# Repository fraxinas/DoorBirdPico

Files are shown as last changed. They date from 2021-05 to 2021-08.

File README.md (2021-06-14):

# DoorBirdPico

(CC) 2021 by Andreas Frisch <fraxinas@purplegecko.de>

## OwO what's this?

**`DoorBirdPico` is a custom Raspberry Pi Pico PCB design and code to add functionality to the DoorBird Voip entryphone.**

## Hardware Features

- ports for 3 RGB-lit doorbell buttons
- ports for 2 reed sensors (door/letterbox)
- hardware debouncing
- power / UART communication with Doorbird D2100E
- 2 input ports for the Doorbird relays
- 1 potential-free relay output (for door opener)
- RS485 transceiver

## Software

- using Rasperry Pi Pico C API
- interrupt services routines for buttons
- color-fading PWM

## Project Diary

| Date | Version | Milestone |
| :--- | :--- | :--- |
| 2021-04-06 | | Pico on Breadboard, pushbutton irq & pwm |
| 2021-04-13 | | Implemented UART communication with Doorbird |
| 2021-04-16 | | Started git repository |
| 2021-05-12 | v0.1 | Commission of 1st prototype PCB with aisler.net |
| 2021-06-02 | v0.1 | Received prototype PCB |
| 2021-06-04 | v0.1 | Assembling of prototype PCB |
| 2021-06-06 | v0.2 | Software is essentially ready |

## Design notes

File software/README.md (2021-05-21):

# DoorBirdPico Software

(CC) 2021 by Andreas Frisch <fraxinas@purplegecko.de>

## Prerequisites
Build requirements:
* `cmake`
* `gcc-arm-none-eabi`
* `meta-group-base-devel` (Arch) / `build-essential` (debian)

### Raspberry Pi Pico SDK
* get https://github.com/raspberrypi/pico-sdk
* build following readme
* `export PICO_SDK_PATH="/your-pico-sdk-path"`
 
## Building
```
cd software
cmake . -B build/
cd build
make
```

## Programming
* use https://github.com/raspberrypi/picotool
```
sudo /path-to/picotool/build/picotool load doorbirdpico.uf2
```

## Documentation of Doorbird UART Communication
* UART baud rate is 9600
* startup sequence needs to be answered with registration string within 2 cycles

| Bytes (HEX) | ASCII | Direction | Command |
| :--- | :--- | :--- | :--- |
| 0x0201 | [STX][SOH] | Main -> PICO | Startup sequence |
| 0x4D54545F31345F3030315F3030310D0A | MTT_14_001_001\r\n | PICO -> Main | Registration as Multi Tenant Module |
| 0x313031230D0A | 101#\r\n | PICO -> Main | Button 1 pressed |
| 0x313032230D0A | 102#\r\n | PICO -> Main | Button 2 pressed |
| 0x313...230D0A | 1nn#\r\n | PICO -> Main | Button n pressed |
| 0x313134230D0A | 114#\r\n | PICO -> Main | Button 14 pressed |

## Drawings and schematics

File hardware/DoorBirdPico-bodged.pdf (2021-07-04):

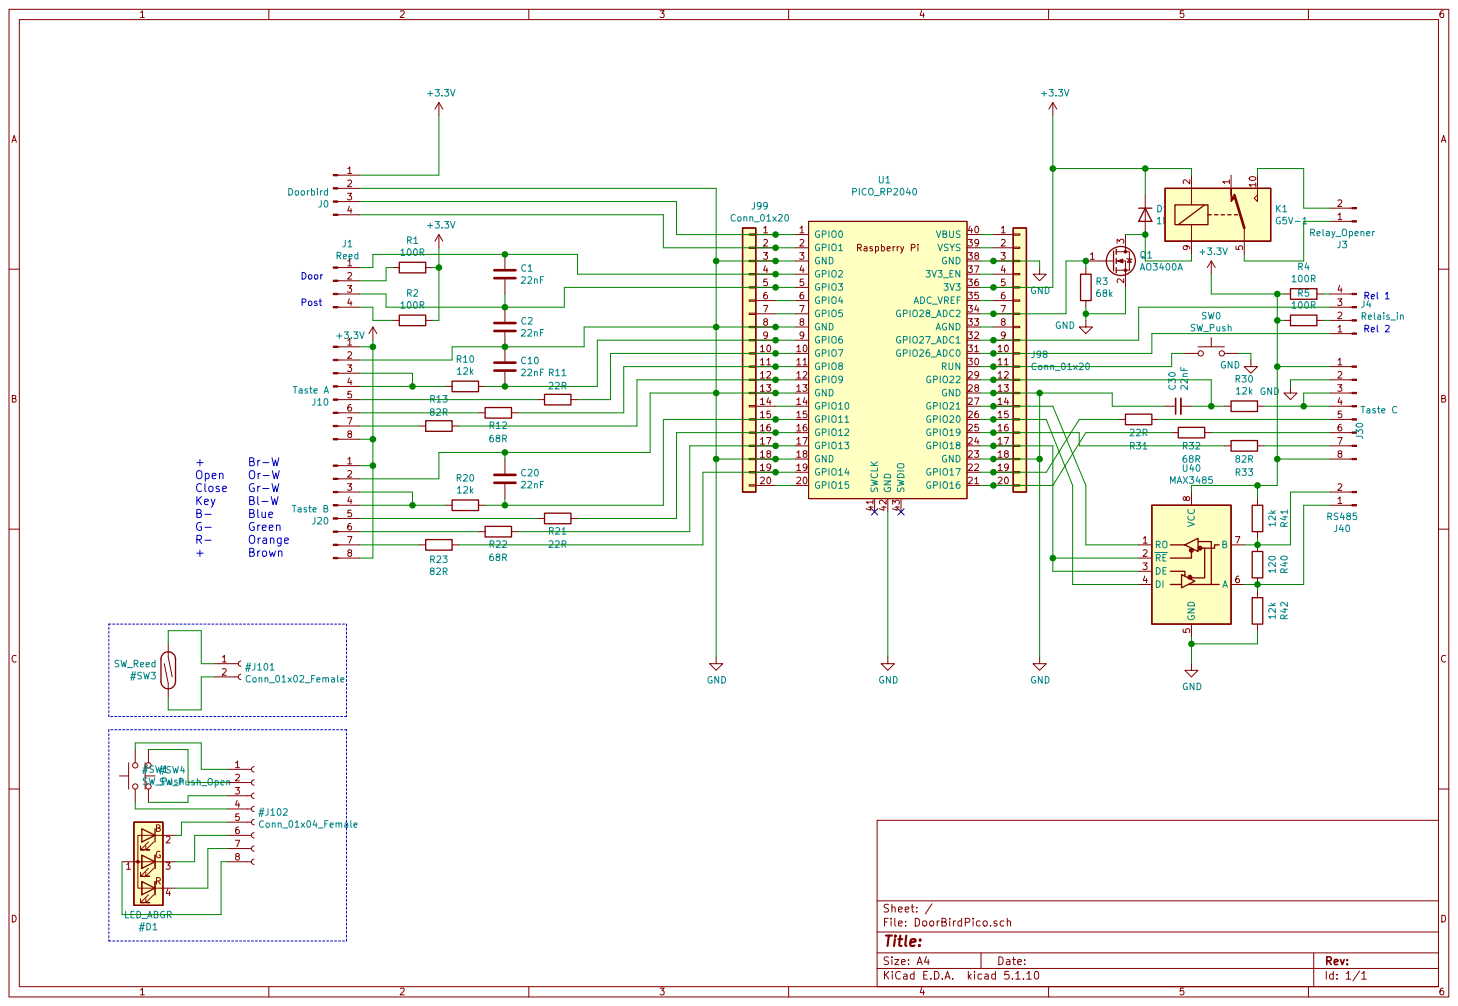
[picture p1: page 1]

10 | 10
11 | 11
12 | 12
13 | 13
14 | 14
15 | 15

17 | 17
18 | 18
19 | 19
20 | 20

Id: 1/1 Title: File: DoorBirdPico.sch Sheet: /

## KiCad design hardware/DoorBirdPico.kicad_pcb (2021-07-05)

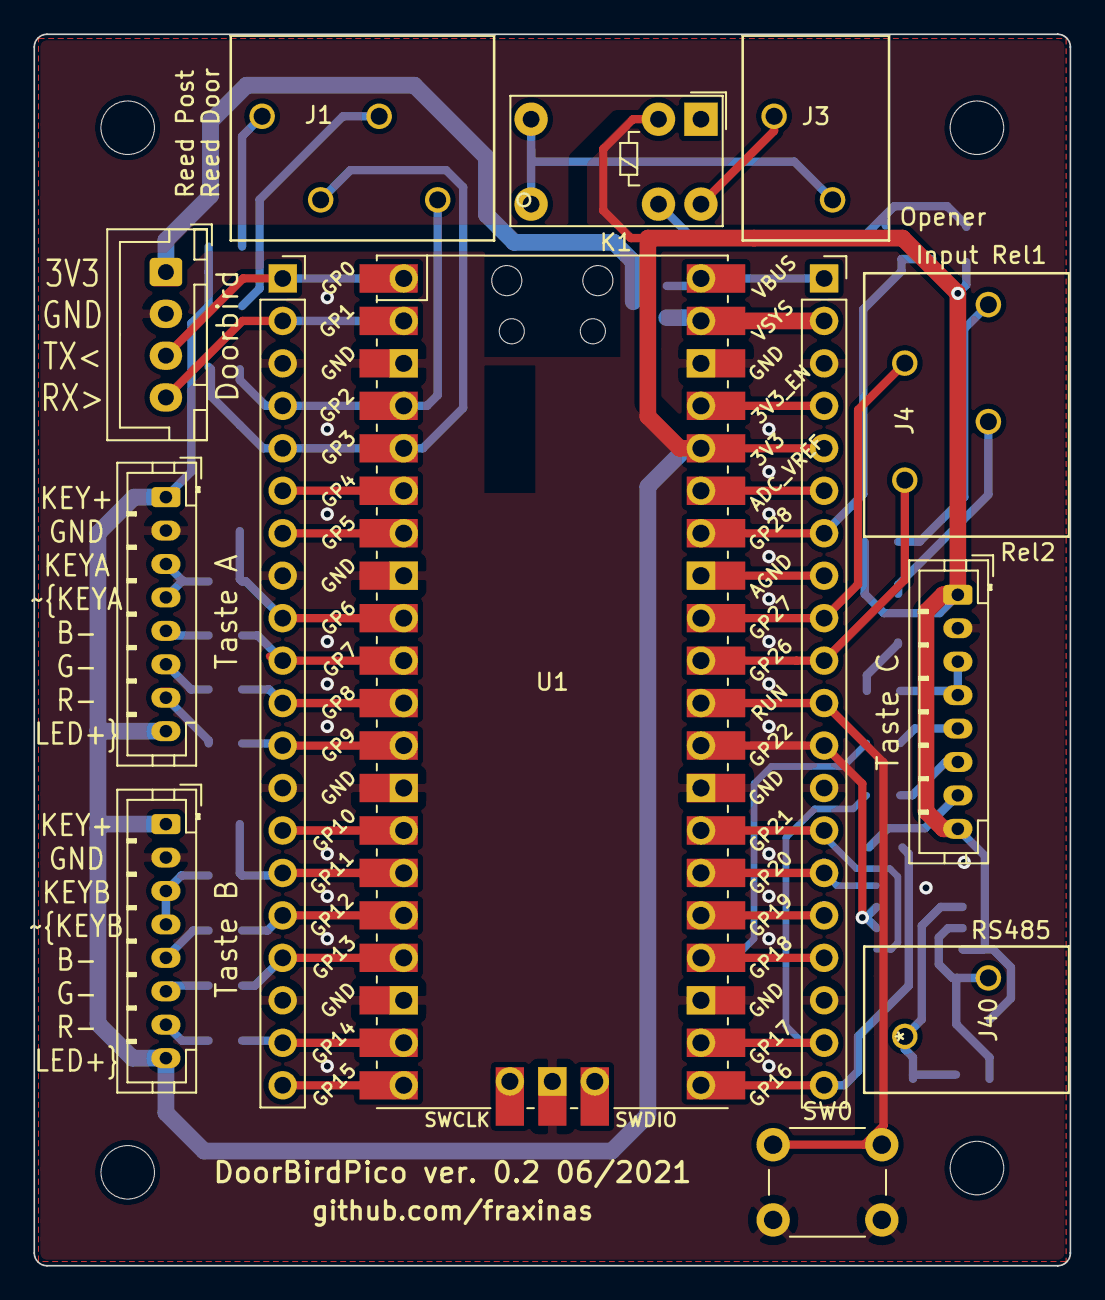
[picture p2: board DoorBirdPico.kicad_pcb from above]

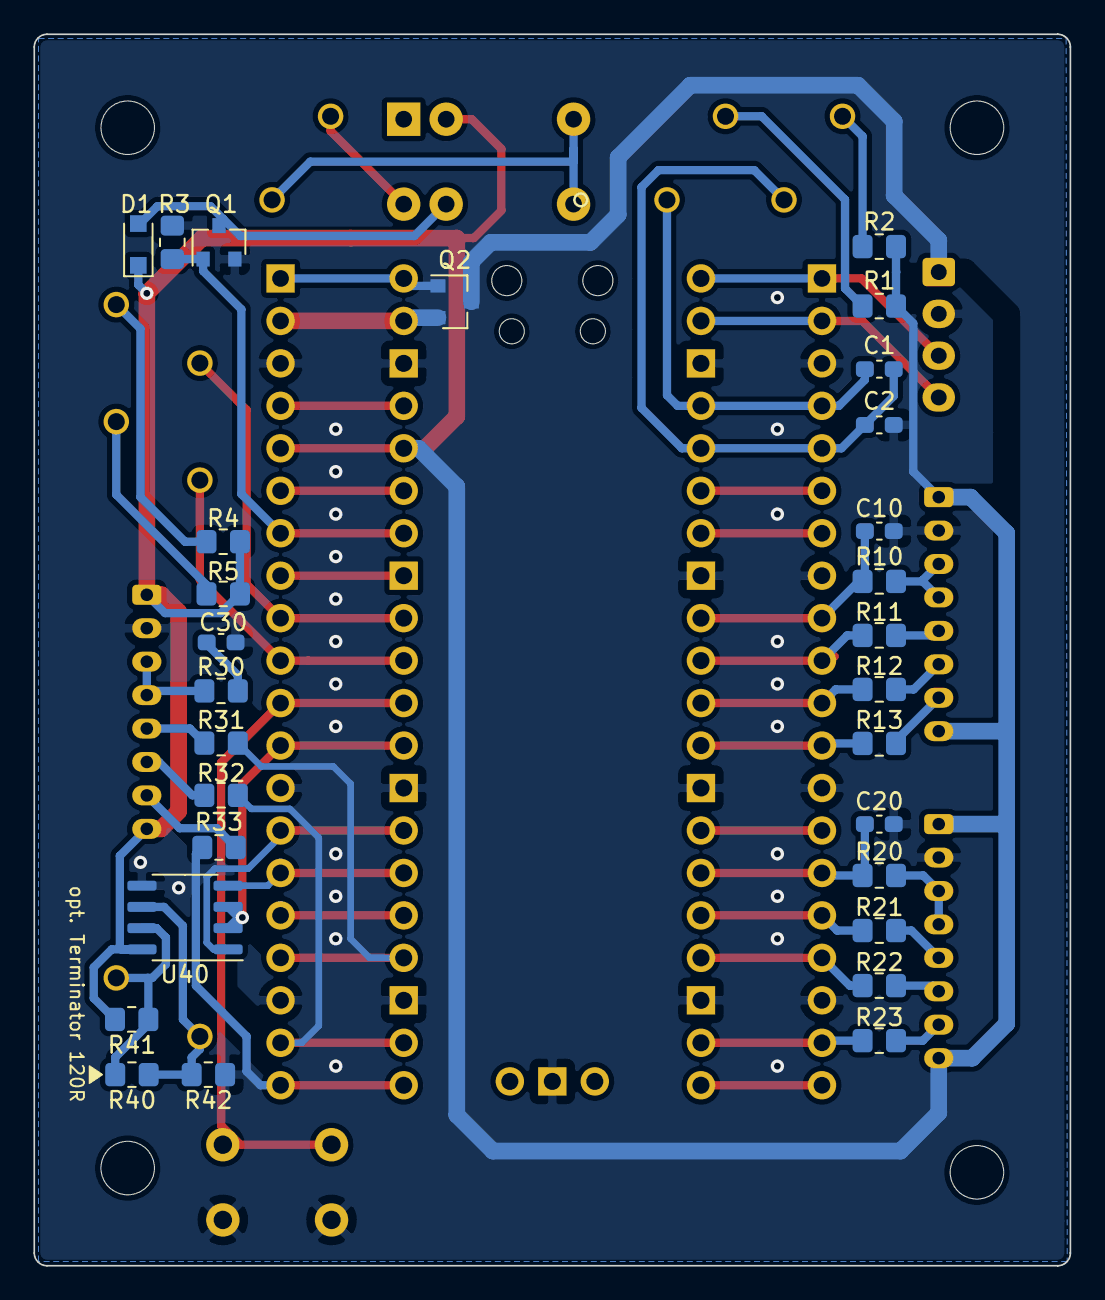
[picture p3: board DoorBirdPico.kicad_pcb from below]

Board: 2 copper layers, 62.0 x 73.7 mm, 42 parts (29 on the bottom side), 57 nets.

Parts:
C1, C2, C10, C20, C30: 22nF; C_0603_1608Metric_Pad1.08x0.95mm_HandSolder
D1: 1N4148WS; D_SOD-323_HandSoldering
J0: Doorbird; JST_XH_B4B-XH-A_1x04_P2.50mm_Vertical
J1: Reed; 250-204
J3: Relay_Opener; 250-202
J4: Relais_in; 250-204
J10: Taste A; JST_PH_B8B-PH-K_1x08_P2.00mm_Vertical
J20: Taste B; JST_PH_B8B-PH-K_1x08_P2.00mm_Vertical
J30: Taste C; JST_PH_B8B-PH-K_1x08_P2.00mm_Vertical
J40: RS485; 250-202
J98, J99: Conn_01x20; PinSocket_1x20_P2.54mm_Vertical
K1: G5V-1; Relay_SPDT_Omron_G5V-1
Q1: AO3400A; SOT-23
Q2: AO3401A; SOT-23
R1, R2, R4, R5: 100R; R_0805_2012Metric_Pad1.20x1.40mm_HandSolder
R3: 68k; R_0805_2012Metric_Pad1.20x1.40mm_HandSolder
R10, R20, R30, R41, R42: 12k; R_0805_2012Metric_Pad1.20x1.40mm_HandSolder
R11, R21, R31: 22R; R_0805_2012Metric_Pad1.20x1.40mm_HandSolder
R12, R22, R32: 68R; R_0805_2012Metric_Pad1.20x1.40mm_HandSolder
R13, R23, R33: 82R; R_0805_2012Metric_Pad1.20x1.40mm_HandSolder
R40: 120; R_0805_2012Metric_Pad1.20x1.40mm_HandSolder
SW0: SW_Push; SW_PUSH_6mm_H5mm
U1: PICO_RP2040; RPi_Pico_SMD_TH
U40: MAX3485; SO-8_3.9x4.9mm_P1.27mm

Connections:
+3V3: D1.1, J10.1, J10.8, J20.1, J20.8, J30.1, J30.8, J98.5, K1.2, R1.1, R2.1, R4.2, R5.2, R41.1, U1.36, U40.8
GND: C2.2, C10.1, C20.1, J0.2, J10.2, J20.2, J30.2, J98.3, J98.13, J98.18, J99.3, J99.8, J99.13, J99.18, Q1.2, R3.2, R42.2, SW0.2, U1.3, U1.8, U1.13, U1.18, U1.23, U1.28, U1.38, U1.42, U40.5
unnamed: C1.1, J1.1, J99.4, U1.4
unnamed: C1.2, C2.1, J1.3, J99.5, U1.5
unnamed: C10.2, J99.9, R10.1, U1.9
unnamed: C20.2, J99.15, R20.1, U1.15
unnamed: C30.2, R30.1
unnamed: D1.2, K1.9, Q1.3
unnamed: J0.1, Q2.3
unnamed: J0.3, J99.1, U1.1
unnamed: J0.4, J99.2, U1.2
unnamed: J1.2, R1.2
unnamed: J1.4, R2.2
unnamed: J3.1, K1.5, K1.6
unnamed: J3.2, K1.10
unnamed: J4.1, J98.10, U1.31
unnamed: J4.2, R5.1
unnamed: J4.3, J98.9, U1.32
unnamed: J4.4, R4.1
unnamed: J10.3, J10.4, R10.2
unnamed: J10.5, R11.1
unnamed: J10.6, R12.1
unnamed: J10.7, R13.1
unnamed: J20.3, J20.4, R20.2
unnamed: J20.5, R21.1
unnamed: J20.6, R22.1
unnamed: J20.7, R23.1
unnamed: J30.3, J30.4, R30.2
unnamed: J30.5, R31.1
unnamed: J30.6, R32.1
unnamed: J30.7, R33.1
unnamed: J40.1, R40.2, R42.1, U40.6
unnamed: J40.2, R40.1, R41.2, U40.7
unnamed: J98.1, Q2.1, U1.40
unnamed: J98.2, Q2.2, U1.39
unnamed: J98.4, U1.37
unnamed: J98.6, U1.35
unnamed: J98.7, Q1.1, R3.1, U1.34
unnamed: J98.8, U1.33
unnamed: J98.11, SW0.1, U1.30
unnamed: J98.12, U1.29, U40.2, U40.3
unnamed: J98.14, U1.27, U40.1
unnamed: J98.15, U1.26, U40.4
unnamed: J98.16, U1.25
unnamed: J98.17, R31.2, U1.24
unnamed: J98.19, R32.2, U1.22
unnamed: J98.20, R33.2, U1.21
unnamed: J99.6, U1.6
unnamed: J99.7, U1.7
unnamed: J99.10, R11.2, U1.10
unnamed: J99.11, R12.2, U1.11
unnamed: J99.12, R13.2, U1.12
unnamed: J99.14, U1.14
unnamed: J99.16, R21.2, U1.16
unnamed: J99.17, R22.2, U1.17
unnamed: J99.19, R23.2, U1.19
unnamed: J99.20, U1.20

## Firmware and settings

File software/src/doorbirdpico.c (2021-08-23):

#include "doorbirdpico.h"

void on_uart_rx()
{
    printf("on_uart_rx... ");
    if (uart_is_readable(UART_ID))
        on_doorbird_rx();

    if (uart_is_readable(RS485_ID))
        on_rs485_rx();
}

void on_doorbird_rx()
{
    printf("on_doorbird_rx... ");
    while (uart_is_readable(UART_ID))
    {
        uint8_t ch = uart_getc(UART_ID);
        printf("0x%02X ", ch);
        if (ch == 0x02)
        {
            ch = uart_getc(UART_ID);
            printf("%02X\n", ch);
            if (ch == 0x01)
            {
                if (uart_is_writable(UART_ID))
                {
                    printf("received startup bytes from Doorbird. Sending UART_INIT_SEQUENCE...\n");
                    uart_puts(UART_ID, UART_INIT_SEQUENCE);
                    printf("'%s' sent successfully!\n", UART_INIT_SEQUENCE);
                    // setup_uart(true);
                    return;
                }
            }
        }
    }
}

rs485_key_t rs485_key_from_str (char *msg)
{
    rs485_key_t key = RS485_K_NONE;
    if (strlen(msg) <= RS485_KEY_LEN+1)
    {
        printf("RS485: buffer too short!\n");
        return key;
    }
    if (msg[RS485_KEY_LEN] != '=')
    {
        printf("RS485: can't parse KEY=VALUE command!\n");
        return key;
    }
    for (key; key < RS485_K_LAST; key++)
    {
        if (strncmp(msg, rs485_key_str[key], RS485_KEY_LEN) == 0)
            return key;
    }
    printf("RS485: unhandled key\n");
    return RS485_K_NONE;
}

void on_rs485_rx()
{
    uint32_t now = time_us_32();
    uint32_t start = now;
    uint8_t buf[RS485_BUF_LEN+1];
    uint8_t p = 0;
    uint8_t ch = ' ';
    uart_set_irq_enables(RS485_ID, false, false);
    //printf("on_rs485_rx...");

    while (p < RS485_BUF_LEN && now < start+RS485_READ_TIMEOUT)
    {
        now = time_us_32();
        if (uart_is_readable(RS485_ID))
        {
            ch = uart_getc(RS485_ID);
            if (ch == 0)
            {
                uart_set_irq_enables(RS485_ID, true, false);
                return;
            }
            // printf("%02X", ch);
            if (ch == '\n' || ch == '\r')
            {
                p++;
                break;
            }
            buf[p++] = ch;
        }
    }
    buf[p] = '\0';

    multicore_fifo_push_blocking((uintptr_t) &mc_handle_rs485_command);
    multicore_fifo_push_blocking((uintptr_t) &buf);

    int ret = multicore_fifo_pop_blocking();
    uart_set_irq_enables(RS485_ID, true, false);
}

bool mc_handle_rs485_command(char *buf)
{
    rs485_key_t key;
    if (strlen(buf) == 1)
        return false;

    printf("\r\nRS485: received '%s' from knxadapter\n", buf);

    key = rs485_key_from_str (buf);

    uint8_t *val = buf+RS485_KEY_LEN+1;
    switch (key)
    {
        case RS485_K_LOCKSTATE:
        {
            lock_state_t new_state = LOCK_S_UNKNOWN;
            if (strcmp(val, lock_state_str[LOCK_S_LOCKED]) == 0)
            {
                new_state = LOCK_S_LOCKED;
            } else if (strcmp(val, lock_state_str[LOCK_S_UNLOCKED]) == 0)
            {
                new_state = LOCK_S_UNLOCKED;
            }
            if (new_state != LOCK_S_UNKNOWN) {
                printf("RS485: New lock state set (previous state: %s) -> ", lock_state_str[lock_state]);
                set_key_c_color(LOCK_A_ACTUATED);
                add_alarm_in_ms(DELAY_ACTUATED_LOCK_MS, actuated_lock_alarm_cb, (void*) new_state, false);
                return true;
            }
            printf("RS485: unhandled value '%s'!\n", val);
            return false;
            break;
        }
        case RS485_K_BUZZER:
        {
            int buzzer = atoi(val);
            printf("RS485: %s Buzzer ", buzzer ? "enable" : "disable");
            gpio_put(PIN_RELAY_OUT, buzzer);
            if (buzzer)
                add_alarm_in_ms(BUZZER_SAFETY_MS, buzzer_alarm_cb, NULL, false);
            break;
        }
        case RS485_K_NONE:
        {
            return false;
        }
        case RS485_K_BRIGHTNESS:
        {
            global_brightness = atoi(val);
            printf("RS485: Brightness %d\r\n", global_brightness);
            for (uint8_t i = 0; i < MAX_PWM_LEDS; i++)
            {
                if (pwm_leds[i].led_out)
                {
                    uint16_t level = get_gamma(pwm_leds[i].val_init);
                    pwm_set_gpio_level(pwm_leds[i].led_out, level);
                }
            }
            break;
        }
        case RS485_K_COLOR:
        {
            char *keypos = val, *keyctx;
            char *bndpos, *bndctx;
            char *valpos, *valctx;
            int pin_idx = 0;
            // Command Syntax: COLOR=R,G,B/R,G,B;R,G,B/R,G,B
            //                   KEY A init/end ; init/end KEY B
            // printf("RS485: Color previous (R, G, B) values: KEY A init=(%d, %d, %d) end=(%d, %d, %d)\t",
            // pwm_leds[0].val_init, pwm_leds[1].val_init, pwm_leds[2].val_init, pwm_leds[0].val_end, pwm_leds[1].val_end, pwm_leds[2].val_end);
            // printf("KEY B init=(%d, %d, %d) end=(%d, %d, %d)\r\n",
            // pwm_leds[3].val_init, pwm_leds[4].val_init, pwm_leds[5].val_init, pwm_leds[3].val_end, pwm_leds[4].val_end, pwm_leds[5].val_end);

            for (int key_idx = 0; key_idx <= 1; key_idx++)
            {
                keypos = strtok_r(val,";", &keyctx);
                // printf("\r\n keypos='%s'", keypos);
                int pin_min_idx = pin_idx;
                int pin_max_idx = pin_idx+3;
                // read R, G, B initial values for key

                bndpos = strtok_r(keypos,"/", &bndctx);
                // printf("\r\n valpos1='%s'", bndpos);
                for (pin_idx=pin_min_idx; pin_idx < pin_max_idx; pin_idx++)
                {
                    valpos = strtok_r(bndpos,",", &valctx);
                    uint8_t val_init = atoi(valpos);
                    pwm_leds[pin_idx].val_init = val_init;
                    // printf("[%d]=%d\t", pin_idx, val_init);
                    uint16_t level = get_gamma(val_init);
                    pwm_set_gpio_level(pwm_leds[pin_idx].led_out, level);
                    bndpos = NULL;
                }

                bndpos = strtok_r(NULL,"/", &bndctx);
                // printf("\r\n valpos2='%s'", bndpos);
                for (pin_idx=pin_min_idx; pin_idx < pin_max_idx; pin_idx++)
                {
                    valpos = strtok(bndpos,",");
                    pwm_leds[pin_idx].val_end = atoi(valpos);
                    // printf("[%d]=%d\t", pin_idx, pwm_leds[pin_idx].val_end);
                    // printf("Color[%d] pin=%i val_end=%d)\r\n", key_idx, pin_idx, pwm_leds[pin_idx].val_end);
                    bndpos = NULL;
                }
                val = NULL;
            }
            printf("RS485: New Colors (R, G, B) values: KEY A init=(%d, %d, %d) end=(%d, %d, %d)\t",
            pwm_leds[0].val_init, pwm_leds[1].val_init, pwm_leds[2].val_init, pwm_leds[0].val_end, pwm_leds[1].val_end, pwm_leds[2].val_end);
            printf("KEY B init=(%d, %d, %d) end=(%d, %d, %d)\r\n",
            pwm_leds[3].val_init, pwm_leds[4].val_init, pwm_leds[5].val_init, pwm_leds[3].val_end, pwm_leds[4].val_end, pwm_leds[5].val_end);
            break;
        }
        default:
            printf("command '%s' (%d) from knxadapter unhandled\n", rs485_key_str[key], key);
            return false;
    }
    return true;
}

void uart_send_code(char *code)
{
    uart_puts(UART_ID, code);
    uart_puts(UART_ID, "\r\n");
}

void rs485_send_msg(rs485_key_t key, const char* val)
{
    printf("RS485: send msg ");
    gpio_put(RS485_DRIVER_ENABLE_PIN, 1);
    char msg[RS485_BUF_LEN];
    snprintf (msg, RS485_BUF_LEN, "%s=%s\r\n\r\n", rs485_key_str[key], val);
    uart_write_blocking	(RS485_ID, msg, strlen(msg));
    printf("%s", msg);
    gpio_put(RS485_DRIVER_ENABLE_PIN, 0);
}

uint8_t get_active_led_count()
{
    uint8_t count = 0;
    for (uint8_t i; i < MAX_PWM_LEDS; i++)
    {
        if (pwm_leds[i].active)
            count++;
    }
    return count;
}

void key_callback(uint gpio)
{
    float divider;
    uint8_t i = 0;

    printf("key_callback(%d) ", gpio);
    switch (gpio)
    {
        case PIN_A_KEY:
            uart_send_code(KEY_A_CODE);
            printf("Key A rang\r\n");
            break;
        case PIN_B_KEY:
            uart_send_code(KEY_B_CODE);
            printf("Key B rang\r\n");
            break;
    }

    for (i; i < MAX_PWM_LEDS; i++)
    {
        pwm_led_t p = pwm_leds[i];
        if (p.key_in == gpio && p.val_init != p.val_end)
        {
            printf("activate LED on pin %d ", p.led_out);
            pwm_leds[i].active = true;
            pwm_leds[i].cycle = p.cycle % 2 ? 1 : 0;
        }
    }

    divider = (float)get_active_led_count() * PWM_LED_INIT_DIV;
    // divider = PWM_LED_INIT_DIV;
    printf("start pwm with divider %.2f ", divider);
    // Set divider, reduces counter clock to sysclock/this value
    pwm_config_set_clkdiv(&pwm_conf, divider);

    for (i = 0; i < MAX_PWM_LEDS; i++)
    {
        pwm_led_t p = pwm_leds[i];
        if (pwm_fading) {
            printf("don't re-init pwm because it's already running!\r\n");
        }
        if (p.active)
        {
            pwm_leds[i].fade = p.val_init;
            if ((pwm_hw->inte & 1u << p.slice_num) == false)
            {
                printf("initializing pwm slice %d for LED on pin %d\r\n", p.slice_num, p.led_out);
                pwm_set_irq_enabled(p.slice_num, true);
                pwm_init(p.slice_num, &pwm_conf, true);
            } else {
                printf("don't re-init pwm slice %d for LED on pin %d because it's already running!\r\n", p.slice_num, p.led_out);
            }
        }
    }
}

void on_pwm_wrap()
{
    uint8_t i = 0;

    printf("on_pwm_wrap() ");

    for (i = 0; i < MAX_PWM_LEDS; i++)
    {
        pwm_led_t p = pwm_leds[i];
        uint16_t level;
        bool do_clear_slice = true;

        // printf("[%d]=", i);

        if (!p.led_out)
            continue;

        // printf("slice=%i ", p.slice_num);

        for (uint8_t j = 0; j < MAX_PWM_LEDS; j++)
        {
            if (p.slice_num == pwm_leds[j].slice_num && i != j && pwm_leds[j].active)
            {
                printf(" {X} ", p.slice_num, i, j);
                do_clear_slice = false;
            }
        }

        if (do_clear_slice) {
            // Clear the interrupt flag that brought us here
            pwm_clear_irq(p.slice_num);
        }

        if (p.active) {
            printf("[%d]: ", i);
            int8_t dir = p.val_end > p.val_init ? (+1) : (-1);
            printf("c=%u f=%u %d  ", pwm_leds[i].cycle, pwm_leds[i].fade, dir);

            if (pwm_leds[i].cycle % 2 == 0)
            {
                if (pwm_leds[i].fade == p.val_end)
                {
                    pwm_leds[i].cycle += 1;
                } else {
                    pwm_leds[i].fade += dir;
                }

            }
            else
            {
                if (pwm_leds[i].fade == p.val_init)
                {
                    pwm_leds[i].cycle += 1;
                } else {
                    pwm_leds[i].fade -= dir;
                }
            }
            if (pwm_leds[i].cycle == PWM_LED_CYCLES)
            {
                // if button still pressed, start over with cycles
                if (gpio_get(p.key_in)) {
                    pwm_leds[i].cycle = 0;
                    continue;
                }

                uint8_t num_active = get_active_led_count()-1;
                // float divider = (float)num_active * PWM_LED_INIT_DIV;
                float divider = PWM_LED_INIT_DIV;
                printf(" i=%d finished. num_active=%u ", i, num_active);
                pwm_leds[i].cycle = 0;
                pwm_leds[i].active = false;
                bool do_stop_fade = true;

                for (uint8_t j = 0; j < MAX_PWM_LEDS; j++)
                {
                    pwm_led_t q = pwm_leds[j];
                    if (q.active) {
                        printf("setting new divider %.2f for gpio %d\n", divider, p.led_out);
                        pwm_config_set_clkdiv(&pwm_conf, divider);
                        pwm_init(q.slice_num, &pwm_conf, true);
                        if ((p.slice_num == q.slice_num && i != j)/* || (p.key_in == q.key_in)*/) {
                            printf("don't stop fading slice %d on led [%d] because [%d] is still active\r\n", p.slice_num, i, j);
                            do_stop_fade = false;
                        }
                    }
                }
                level = get_gamma(p.val_init);
                if (do_stop_fade) {
                    printf("...stop fading\r\n");
                    pwm_set_irq_enabled(p.slice_num, false);
                    pwm_fading = false;
                }
                continue;
            } else {
                level = get_gamma(pwm_leds[i].fade);
            }
            pwm_set_gpio_level(p.led_out, level);
            printf("%hu ", level);
        }
    }
    printf("\r\n");
}

void set_key_c_color(lock_action_t action)
{
    bool r, g, b = 1;

    switch (action)
    {
    case LOCK_A_OFF: // black
        r = 1;
        g = 1;
        b = 1;
        break;
    case LOCK_A_LOCKING: // purple
        r = 0;
        g = 1;
        b = 0;
        break;
    case LOCK_A_LOCKED: // red
        r = 0;
        g = 1;
        b = 1;
        break;
    case LOCK_A_LEAVING: // blue
        r = 1;
        g = 1;
        b = 0;
        break;
    case LOCK_A_UNLOCKING: // cyan
        r = 1;
        g = 0;
        b = 0;
        break;
    case LOCK_A_UNLOCKED: // green
        r = 1;
        g = 0;
        b = 1;
        break;
    case LOCK_A_ACTUATED: // yellow
        r = 0;
        g = 0;
        b = 1;
        break;
    case LOCK_A_PRESSED: // white
        r = 0;
        g = 0;
        b = 0;
        break;
    default:
        break;
    }
    gpio_put(PIN_C_RED, r);
    gpio_put(PIN_C_GREEN, g);
    gpio_put(PIN_C_BLUE, b);
}

int64_t buzzer_alarm_cb(alarm_id_t id, void *user_data)
{
    if (gpio_get(PIN_RELAY_OUT)) {
        printf("buzzer_alarm_cb -> Buzzer off!\r\n");
        gpio_put(PIN_RELAY_OUT, 0);
    }
    return 0;
}

int64_t actuated_lock_alarm_cb(alarm_id_t id, void *user_data)
{
    lock_state_t new_state;
    if (user_data) {
        // state received via RS485
        new_state = (lock_state_t)user_data;
    } else {
        // relais toggled
        new_state = gpio_get(PIN_RELAY_IN2) ? LOCK_S_LOCKED : LOCK_S_UNLOCKED;
    }
    printf("actuated_lock_alarm_cb -> new_state: %s\r\n", lock_state_str[new_state]);
    if (new_state == LOCK_S_LOCKED)
    {
        set_key_c_color(LOCK_A_LOCKED);
    }
    else if (new_state == LOCK_S_UNLOCKED)
    {
        set_key_c_color(LOCK_A_UNLOCKED);
        if (gpio_get(PIN_RELAY_IN1))
        {
            printf("Door got unlocked & Relay 1 still on -> Buzzer on!\r\n");
            gpio_put(PIN_RELAY_OUT, 1);
            add_alarm_in_ms(BUZZER_SAFETY_MS, buzzer_alarm_cb, NULL, false);
        }
        if (lock_state == LOCK_S_WAITING_FOR_UNLOCK)
        {
            printf("Door got unlocked while waiting -> Buzzer on for %d ms!\r\n", BUZZER_MS);
            gpio_put(PIN_RELAY_OUT, 1);
            add_alarm_in_ms(BUZZER_MS, buzzer_alarm_cb, NULL, false);
        }
    }
    lock_state = new_state;
    return 0;
}

int64_t delayed_lock_alarm_cb(alarm_id_t id, void *user_data)
{
    printf("...delayed_lock_alarm_cb(%d) send %s\r\n", (int)id, LOCK_CODE);
    send_locking_action(LOCK_A_LOCKING);
    return 0;
}

void send_locking_action(lock_action_t action)
{
    set_key_c_color(action);

    if (action == LOCK_A_LOCKING) {
        uart_send_code(LOCK_CODE);
    } else if (action == LOCK_A_UNLOCKING) {
        uart_send_code(UNLOCK_CODE);
    }

    rs485_send_msg(RS485_K_LOCKACTION, lock_action_str[action]);
}

int64_t lock_key_pressed_cb(alarm_id_t id, void *user_data)
{
    printf("...lock_key_pressed_cb(%d) ", (int)id);

    bool long_pressed = gpio_get(PIN_C_KEY);

    if (long_pressed)
    {
        printf("LONG pressed -> LOCK immediately (send %s)\r\n", LOCK_CODE);
        send_locking_action(LOCK_A_LOCKING);
    }
    else
    {
        printf("short pressed -> LOCK delayed ");
        add_alarm_in_ms(DELAY_LEAVING_LOCK_MS, delayed_lock_alarm_cb, NULL, false);
    }

    return 0;
}

void sensor_input(uint gpio, uint32_t events)
{
    static uint32_t last_irq_ts = 0;
    uint32_t now = time_us_32();

    if (now - last_irq_ts > DEBOUNCE_MS * 1000)
    {
        bool beginVal = gpio_get(gpio);
        printf("sensor_input(%d, %02X)=%d...", gpio, events, beginVal);
        busy_wait_us(3000);
        bool RisingEdge = gpio_get(gpio);
        if (beginVal != RisingEdge || events == 0x0C)
        {
            printf(" was a glitch! ignored.\r\n");
            last_irq_ts = now;
            return;
        }
        bool FallingEdge = !RisingEdge;
        printf(" is %s\t", RisingEdge ? "RisingEdge" : "FallingEdge");

        switch (gpio)
        {
        case PIN_A_KEY:
        case PIN_B_KEY:
            if (RisingEdge)
                key_callback(gpio);
            break;
        case PIN_C_KEY:
            printf("lock toggle pressed in state %s ", lock_state_str[lock_state]);
            if (!RisingEdge)
                break;
            if (lock_state != LOCK_S_UNLOCKED)
            {
                printf(" -> UNLOCK (send %s)\r\n", UNLOCK_CODE);
                send_locking_action(LOCK_A_UNLOCKING);
            }
            else
            {
                set_key_c_color(LOCK_A_PRESSED);
                add_alarm_in_ms(LONG_PRESS_MS, lock_key_pressed_cb, NULL, false);
            }
            break;
        case PIN_REED_LETTER:
            if (FallingEdge)
            {
                printf("Letterbox opened (send %s)\r\n", LETTER_CODE);
                uart_send_code(LETTER_CODE);
            }
            door_state_t letter_state = RisingEdge ? DOOR_CLOSED : DOOR_OPEN;
            rs485_send_msg(RS485_K_LETTERREED, door_state_str[letter_state]);
            break;
        case PIN_REED_DOOR:
            door_state = RisingEdge ? DOOR_CLOSED : DOOR_OPEN;
            rs485_send_msg(RS485_K_DOORREED, door_state_str[door_state]);
            printf("Reed door toggle -> door_state = %s\r\n", door_state_str[door_state]);
            break;
        case PIN_RELAY_IN1:
            if (FallingEdge)
            {
                printf("Relay 1 falling -> Buzzer off!\r\n");
                gpio_put(PIN_RELAY_OUT, 0);
            }
            else
            {
                if (lock_state == LOCK_S_UNLOCKED)
                {
                    printf("Relay 1 rising -> Buzzer on!\r\n");
                    add_alarm_in_ms(BUZZER_SAFETY_MS, buzzer_alarm_cb, NULL, false);
                    gpio_put(PIN_RELAY_OUT, 1);
                }
                else
                {
                    printf("Relay 1 rising while in LOCKED ");
                    if (DO_UNLOCK_ON_OPEN)
                    {
                        printf(" -> UNLOCK (send %s)...\r\n", UNLOCK_CODE);
                        send_locking_action(LOCK_A_UNLOCKING);
                    }
                    else
                    {
                        printf(" -> waiting for unlocked...\r\n");
                        lock_state = LOCK_S_WAITING_FOR_UNLOCK;
                        send_locking_action(LOCK_A_LEAVING);
                    }
                }
            }
            break;
        case PIN_RELAY_IN2:
            printf("Relay 2 toggle (previous state: %s) -> ", lock_state_str[lock_state]);
            set_key_c_color(LOCK_A_ACTUATED);
            add_alarm_in_ms(DELAY_ACTUATED_LOCK_MS, actuated_lock_alarm_cb, NULL, false);
            break;
        }
    }
    last_irq_ts = now;
}

int setup_irq()
{
    stdio_init_all();
    printf("Hello GPIO IRQ\n");
    gpio_set_irq_enabled_with_callback(PIN_A_KEY, GPIO_IRQ_EDGE_RISE, true, &sensor_input);
    gpio_set_irq_enabled_with_callback(PIN_B_KEY, GPIO_IRQ_EDGE_RISE, true, &sensor_input);
    gpio_set_irq_enabled_with_callback(PIN_C_KEY, GPIO_IRQ_EDGE_RISE, true, &sensor_input);
    gpio_set_irq_enabled_with_callback(PIN_REED_LETTER, GPIO_IRQ_EDGE_FALL | GPIO_IRQ_EDGE_RISE, true, &sensor_input);
    gpio_set_irq_enabled_with_callback(PIN_REED_DOOR, GPIO_IRQ_EDGE_FALL | GPIO_IRQ_EDGE_RISE, true, &sensor_input);
    gpio_set_irq_enabled_with_callback(PIN_RELAY_IN1, GPIO_IRQ_EDGE_FALL | GPIO_IRQ_EDGE_RISE, true, &sensor_input);
    gpio_set_irq_enabled_with_callback(PIN_RELAY_IN2, GPIO_IRQ_EDGE_FALL | GPIO_IRQ_EDGE_RISE, true, &sensor_input);
}
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
int main()
{
    setup_gpio();

    setup_irq();
    setup_uart(false);
    sleep_ms(6000);
    setup_pwm();

    gpio_put(PIN_STATUS, 1);

    multicore_launch_core1(core1_dispatcher);

    // Everything after this point happens in the interrupt handlers,
    // so we can chill here
    while (1)
    {
        gpio_put(PIN_STATUS, 1);
        sleep_ms(250);
        gpio_put(PIN_STATUS, 0);
        sleep_ms(250);
        tight_loop_contents();
    }
}

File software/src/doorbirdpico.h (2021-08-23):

#include <stdio.h>
#include <string.h>
#include <stdlib.h>
#include "pico/stdlib.h"
#include "pico/time.h"
#include "pico/multicore.h"
#include "hardware/gpio.h"
#include "hardware/irq.h"
#include "hardware/pwm.h"
#include "hardware/structs/pwm.h"

#define UART_ID uart0
#define BAUD_RATE 9600
#define UART_TX_PIN 0
#define UART_RX_PIN 1
#define UART_INIT_SEQUENCE "MTT_14_001_001\r\n"

#define PIN_REED_DOOR 2
#define PIN_REED_LETTER 3

#define PIN_A_KEY 6
#define PIN_A_BLUE 7
#define PIN_A_GREEN 8
#define PIN_A_RED 9

#define PIN_B_KEY 11
#define PIN_B_BLUE 12
#define PIN_B_GREEN 13
#define PIN_B_RED 14

#define PIN_C_KEY 22
#define PIN_C_BLUE 17
#define PIN_C_GREEN 16
#define PIN_C_RED 19

#define PIN_RELAY_OUT 28

#define PIN_RELAY_IN1 27
#define PIN_RELAY_IN2 26

#define LONG_PRESS_MS 800
#define DELAY_LEAVING_LOCK_MS 15000
#define DELAY_ACTUATED_LOCK_MS 2500
#define BUZZER_MS 5000
#define BUZZER_SAFETY_MS 10000

#define PIN_STATUS 25

#define KEY_A_CODE "101#"
#define KEY_B_CODE "102#"
#define LOCK_CODE "103#"
#define UNLOCK_CODE "104#"
#define LETTER_CODE "105#"

#define DEBOUNCE_MS 15

#define MAX_PWM_LEDS 6
#define PWM_LED_INIT_DIV 4.0f
#define PWM_LED_CYCLES 8

#define DO_UNLOCK_ON_OPEN true

#define RS485_ID uart1
#define RS485_TX_PIN 20
#define RS485_RX_PIN 21
#define RS485_DRIVER_ENABLE_PIN 18
#define RS485_BUF_LEN 64
#define RS485_KEY_LEN 10
#define RS485_READ_TIMEOUT 1000000/96*(RS485_BUF_LEN+1)

typedef enum{
    RS485_K_NONE,
    RS485_K_LOCKSTATE,
    RS485_K_LOCKACTION,
    RS485_K_BUZZER,
    RS485_K_DOORREED,
    RS485_K_LETTERREED,
    RS485_K_BRIGHTNESS,
    RS485_K_COLOR,
    RS485_K_LAST,
} rs485_key_t;

static const char *rs485_key_str[] = {
    "",
    " LOCKSTATE",
    "LOCKACTION",
    "    BUZZER",
    "  DOORREED",
    "LETTERREED",
    "BRIGHTNESS",
    "     COLOR"
};

typedef enum
{
    DOOR_UNKNOWN,
    DOOR_CLOSED,
    DOOR_OPEN,
} door_state_t;

typedef enum
{
    LOCK_S_UNKNOWN,
    LOCK_S_LOCKED,
    LOCK_S_UNLOCKED,
    LOCK_S_WAITING_FOR_UNLOCK,
} lock_state_t;

typedef enum
{
    LOCK_A_OFF,
    LOCK_A_LOCKING,
    LOCK_A_LOCKED,
    LOCK_A_LEAVING,
    LOCK_A_UNLOCKING,
    LOCK_A_UNLOCKED,
    LOCK_A_ACTUATED,
    LOCK_A_PRESSED,
} lock_action_t;

static const char *door_state_str[] = {
    "UNKNOWN",
    "CLOSED",
    "OPEN",
};

static const char *lock_state_str[] = {
    "UNKNOWN",
    "LOCKED",
    "UNLOCKED",
    "WAITING_FOR_UNLOCK",
};

static const char *lock_action_str[] = {
    "OFF",
    "LOCKING",
    "LOCKED",
    "LEAVING",
    "UNLOCKING",
    "UNLOCKED",
    "ACTUATED",
    "PRESSED",
};

const uint16_t pwm_gamma[] = {
      0,   662,  1320,  1974,  2623,  3267,  3908,  4543,
   5175,  5802,  6424,  7043,  7657,  8266,  8872,  9473,
  10070, 10662, 11251, 11835, 12415, 12990, 13562, 14129,
  14693, 15252, 15807, 16358, 16905, 17447, 17986, 18521,
  19051, 19578, 20101, 20619, 21134, 21645, 22152, 22654,
  23153, 23649, 24140, 24627, 25111, 25590, 26066, 26539,
  27007, 27471, 27932, 28389, 28843, 29292, 29738, 30181,
  30619, 31054, 31486, 31913, 32338, 32758, 33175, 33589,
  33999, 34405, 34808, 35207, 35603, 35996, 36385, 36770,
  37153, 37531, 37907, 38279, 38647, 39013, 39375, 39733,
  40089, 40441, 40790, 41135, 41478, 41817, 42153, 42486,
  42815, 43142, 43465, 43785, 44102, 44416, 44727, 45035,
  45340, 45641, 45940, 46236, 46529, 46818, 47105, 47389,
  47670, 47948, 48223, 48495, 48764, 49031, 49295, 49555,
  49813, 50069, 50321, 50571, 50818, 51062, 51304, 51542,
  51778, 52012, 52243, 52471, 52696, 52919, 53140, 53357,
  53572, 53785, 53995, 54203, 54408, 54610, 54810, 55008,
  55203, 55396, 55586, 55774, 55960, 56143, 56324, 56503,
  56679, 56853, 57024, 57194, 57361, 57525, 57688, 57848,
  58007, 58163, 58316, 58468, 58618, 58765, 58910, 59053,
  59195, 59334, 59471, 59606, 59739, 59870, 59999, 60126,
  60251, 60374, 60495, 60614, 60732, 60847, 60961, 61072,
  61182, 61290, 61397, 61501, 61604, 61705, 61804, 61902,
  61998, 62092, 62184, 62275, 62364, 62451, 62537, 62621,
  62704, 62785, 62865, 62943, 63019, 63094, 63167, 63239,
  63310, 63379, 63446, 63512, 63577, 63640, 63702, 63763,
  63822, 63880, 63937, 63992, 64046, 64099, 64150, 64200,
  64249, 64297, 64344, 64389, 64433, 64476, 64518, 64559,
  64599, 64637, 64675, 64711, 64747, 64781, 64815, 64847,
  64878, 64909, 64938, 64967, 64995, 65024, 65052, 65081,
  65109, 65138, 65166, 65195, 65223, 65251, 65280, 65308,
  65337, 65365, 65394, 65422, 65451, 65479, 65508, 65535
};

typedef struct pwm_led {
    bool active;
    uint key_in;
    uint led_out;
    uint slice_num;
    uint8_t val_init;
    uint8_t val_end;
    uint8_t fade;
    uint8_t cycle;
} pwm_led_t;

door_state_t door_state;
lock_state_t lock_state;
pwm_config pwm_conf;
pwm_led_t pwm_leds[MAX_PWM_LEDS];
bool pwm_fading;
uint8_t global_brightness;

// received data on UART0 or RS485
void on_uart_rx();

// process data from Doorbird
void on_doorbird_rx();

// Send data to Doorbird via UART
void uart_send_code(char *code);

// Get key from RS485 command
rs485_key_t rs485_key_from_str (char *msg);

// process data from knxadapter
void on_rs485_rx();

// Send data to knxadapter via RS485
void rs485_send_msg(rs485_key_t key, const char* val);

// Return amount of active PWM LEDs
uint8_t get_active_led_count();

// Button pressed
void key_callback(uint gpio);

// PWM wrap callback, de/in-crement & set RGB values
void on_pwm_wrap();

// get brightness-adjusted 16-bit PWM gamma value from 8-bit component
uint16_t get_gamma(uint8_t value);

// Set color of inside button
void set_key_c_color(lock_action_t action);

// Turn off buzzer callback
int64_t buzzer_alarm_cb(alarm_id_t id, void *user_data);

// function when lock state relais 2 changed
int64_t actuated_lock_alarm_cb(alarm_id_t id, void *user_data);

// function called after leaving lock delay
int64_t delayed_lock_alarm_cb(alarm_id_t id, void *user_data);

// function which sends (un-)locking codes to UART and RS485
void send_locking_action(lock_action_t action);

// check whether inside key was pressed short or long and lock accordingly
int64_t lock_key_pressed_cb(alarm_id_t id, void *user_data);

// interrupt service routine, debouncer and function router for all inputs
void sensor_input(uint gpio, uint32_t events);

// parse & handle RS485 command on core1
bool mc_handle_rs485_command(char *cmd);

// Setup function for interrupts
int setup_irq();

// Setup function for Inputs and Outputs
int setup_gpio();

// Setup function for RGB PWM
int setup_pwm();

// Setup function for UART communication
int setup_uart(bool enable_rs485);

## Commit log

2021-04-16 hardware: Add initial KiCAD project, schematic & PCB
    [DoorBirdPico.kicad_pcb, DoorBirdPico.sch]
2021-04-16 Schema: Add 3rd RGB button port, 2 relay inputs, 1 relay output
    [DoorBirdPico.sch]
2021-04-17 Schema: Add MAX3485 Transceiver
    [DoorBirdPico.sch]
2021-04-17 PCB: Add RS485 components
    [DoorBirdPico.kicad_pcb]
2021-05-18 Hardware: Add RS485 circuitry resistors
    [DoorBirdPico.kicad_pcb, DoorBirdPico.sch]
2021-05-19 Library: Move footprints into subdir
2021-05-19 Library: Add symbols + footprints for WAGO 250 terminals
2021-05-19 Hardware: Use WAGO 250 Terminals in Schema & PCB
    [DoorBirdPico.kicad_pcb, DoorBirdPico.sch]
2021-05-19 Hardware: Get ready for production
    * Silkscreen label placements
    * D1 handsolderable footprint
    [DoorBirdPico.kicad_pcb, DoorBirdPico.sch]
2021-05-19 Software: Add initial software, LED PWM on keypress
2021-05-19 Software: Implement 2nd Key, implement bidirectional UART
2021-05-21 Software: Add readme, document UART communication
2021-05-21 Software: Use correct Key/LED GPIOs
    [doorbirdpico.c]
2021-05-21 Software: Add relay input and outputs
2021-05-26 Software: Fix & Improve sensor_input function
    [doorbirdpico.c]
2021-05-27 Software: use timers instead of sleeps for yellow light / leaving lock delay
2021-06-01 Schema: Add wire colors to Key connector
    [DoorBirdPico.sch]
2021-06-02 Software: Only use one interrupt service callback, fix typo
    [doorbirdpico.c]
2021-06-04 Software: Enable relay GPIOs and set relay and reed input pulldowns
2021-06-04 Software: Add blinking status LED
2021-06-05 Software: Initialize GPIOs properly, reverse color polarity
    [doorbirdpico.c]
2021-06-05 Software: Add UART sendfunc, rename post->letter, fix lock/unlock key cb
    * DO NOT use sleep in ISR, it will freeze
    [doorbirdpico.c]
2021-06-05 Readme: Add reset button to TODOs
2021-06-06 Software: Fix Key C long pressed detection, refactor color setter
    [doorbirdpico.c]
2021-06-06 Schematic: Use 3V3 pin instead of Vsys
    [DoorBirdPico.sch]
2021-06-06 Schematic: Fix C1
    [DoorBirdPico.sch]
2021-06-06 Schematic: Fix R1, R2, R4, R5 values
    [DoorBirdPico.sch]
2021-06-07 Schematic: Add reset switch
    [DoorBirdPico.sch]
2021-06-08 Software: Implement 16 bit gamma LUT for LED PWM
2021-06-08 Software: refactor key PWM (WIP)
    * this freezes in the pwm_wrap function
2021-06-09 Software: Refactor key LED PWM (WIP)
2021-06-09 Software: Work on PWM handling, fix re-triggering (WIP)
    * Concurrent keys pwm doesn't work properly yet
    [doorbirdpico.c]
2021-06-10 Software: Fix PWM slice handling
    [doorbirdpico.c]
2021-06-10 Software: Implement start and end vals for PWM colors
    * works both ways around (up and down)
    * only works right if multiple Pins have same steps
2021-06-12 Software: Don't re-init PWM on 2nd keypress (workaround slow concurrent operation)
    [doorbirdpico.c]
2021-06-13 PCB: Add Reset button, fix v0.2 TODOs
    [DoorBirdPico.kicad_pcb]
2021-06-26 Software: Try to fix reading from RS485
    [doorbirdpico.c, doorbirdpico.h]
2021-06-29 Software: Try workaround for UART1 init (WIP)
    [doorbirdpico.c, doorbirdpico.h]
2021-06-30 Software: Use explicit timeout for RS485 UART RX
2021-07-01 Software: Fix handling RS485 commands
    * fix syntax in key string array definition
    * disable IRQ while processing RX, reenable afterwards
    [doorbirdpico.c, doorbirdpico.h]
2021-07-01 Software: Fix RS485 RX command terminations
    [doorbirdpico.c]
2021-07-01 Software: switch UART1 & UART0 between Doorbird and RS485
2021-07-03 Software: Add driver enable pin control for RS485
2021-07-03 Schematic: Bodge UART1 RS485 pins
    [DoorBirdPico.sch]
2021-07-03 Software: Change UART Pins to the correct GPIOs
    [doorbirdpico.c, doorbirdpico.h]
2021-07-04 Hardware: Plot bodged schematic
2021-07-05 Schematic: Add P-MOS for decoupling Doorbird VCC from USB Power
    [DoorBirdPico.sch]
2021-07-05 PCB: Add P-MOS for decoupling Doorbird VCC from USB Power
    [DoorBirdPico.kicad_pcb]
2021-07-05 Hardware: Update KiCAD Project file
2021-07-06 Software: Clean up uart init function
2021-07-07 Software: Add COLOR setter command, implement brightness adjustment
    TODO: Concurrent fading, fix PWM init on same slices
    [doorbirdpico.c, doorbirdpico.h]
2021-07-08 Software: Work on PWM fading (WIP)
2021-08-14 Software: Fix RS485 TX line endings
    [doorbirdpico.c]
2021-08-14 Software: Fix double locking on short press, enable unlocking before buzzer
    [doorbirdpico.c, doorbirdpico.h]
2021-08-22 Software: Filter out input pin glitch interrupts, ignore Key C release
    [doorbirdpico.c]
2021-08-23 Software: Add safety watchdog timer for turning off buzzer
    [doorbirdpico.c, doorbirdpico.h]

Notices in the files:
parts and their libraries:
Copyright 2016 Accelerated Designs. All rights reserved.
